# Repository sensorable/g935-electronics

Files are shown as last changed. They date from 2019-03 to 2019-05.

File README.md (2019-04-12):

# Sensorable Open Source Camera
### Electronics and assembly

Sensorable camera is a low power edge computer for smart applications with limited power and bandwidth.
It is based on Samsung G935F smartphone board with auxiliary chassis and electronics.

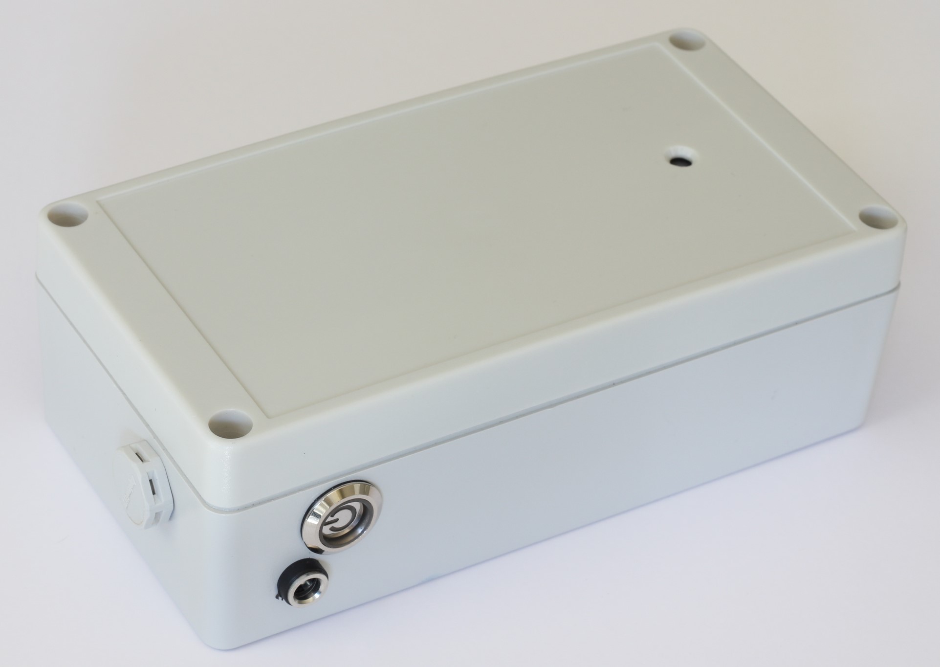
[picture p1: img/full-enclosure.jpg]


**Applications:**
* outdoor security
* remote site monitoring
* beach / nature cams
* traffic monitoring
* vehicle counting
* ALPR / ANPR
* speed control and monitoring

## Main components
* G935F board with a rear camera and antennas
* [custom G935f chassis](https://github.com/sensorable/g935-enclosure)
* [Hammonds IP65 enclosure](https://www.hammfg.com/part/RP1170)
* [auxiliary PSU](https://github.com/sensorable/g935-electronics/tree/master/psu)
* [power](https://github.com/sensorable/g935-electronics/tree/master/pwr-conn) and [USB connectors](https://github.com/sensorable/g935-electronics/tree/master/usb-conn)

The camera can be assembled, programmed, tested and deployed by a sufficiently skilled technician.  

See _BOM-combined.csv_ for the full list of parts.

## Packaging options

* Chassis only for OEM embedding: 155mm x 75mm x 15mm
* Unsealed enclosure for OEM embedding: 165mm x 86mm x 20mm
* Sealed enclosure for external use: 165mm x 86mm x 56mm

The sealed enclosure may include an optional battery pack. See https://github.com/sensorable/batt-pack for more info.

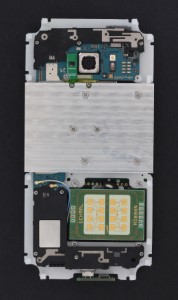
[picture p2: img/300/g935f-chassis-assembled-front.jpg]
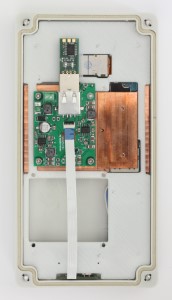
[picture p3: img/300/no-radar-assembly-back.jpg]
 

## Auxiliary components

The chassis has mounting options for a few auxiliary components. They can also be connected externally via USB or RS232.

* Built-in Houston-Radar SS400
* Built-in generic OEM radar
* USB/RS232 adapter
* External Houston-Radar
* External AGD radar

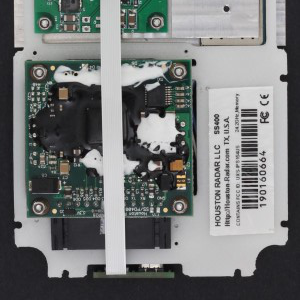
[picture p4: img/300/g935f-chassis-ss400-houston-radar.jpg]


## Ordering and assembly

This is only a high level overview to give you an idea what's involved. We recommend getting in touch with us to help you with your production run.

Check the combined BOM for the full list of components and recommended suppkiers. We tried to minimise the number of suppliers and use only the reputable ones: 

* **Elelctronic parts**: DigiKey
* **Fastenings**: Accu
* **PCB**: JlcPCB
* **PCBA**: JlcPCB or your local PCBA specialist

The final assembly is expected to be done in-house or by a __trusted__ local embedded systems specialist as it involves testing, loading the software and configuring the devices.

See other repositories for the mechanical (chassis) and software (ROM, tools, apps, etc).

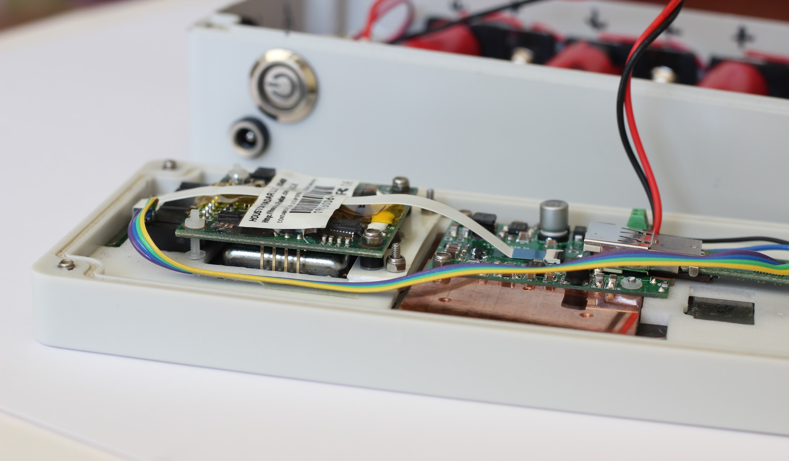
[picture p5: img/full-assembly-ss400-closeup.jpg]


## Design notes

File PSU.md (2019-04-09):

# Sensorable Open Source Camera
### Power Supply Unit

The PSU board converts a single 12v input into multiple voltages needed by the G935F board and auxiliary device. Also, it acts as a connector between a radar, a USB/RS232 converter and the G935F.

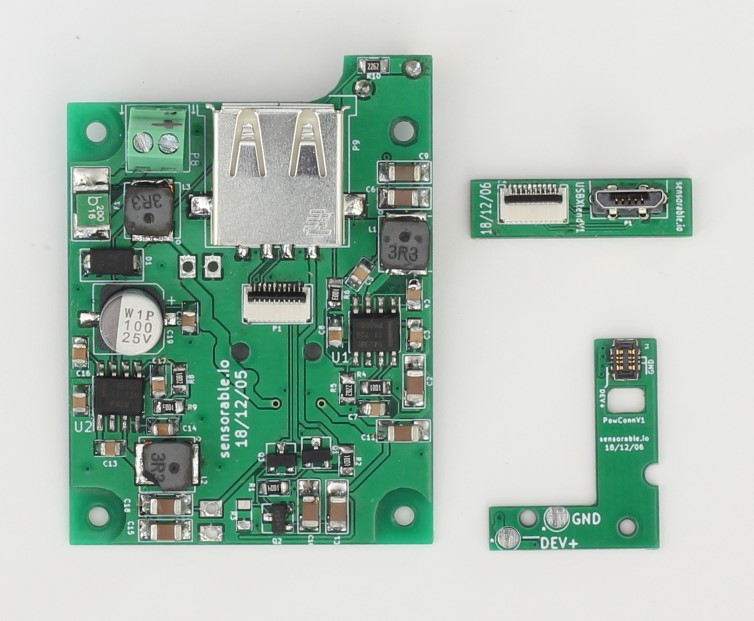
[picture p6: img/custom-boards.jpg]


## Specification

* **Max input voltage:** 14V working voltage
* **Min input voltage:** 6v
* **Max operating current:** 2A
* **Size**: 50mm x 37mm x 9mm

#### Protection

* **Fuse hold/trip current:** 2A/3.5A
* **Input protection:** unipolar Zener diode, 14V working voltage, clamps to 23V @ 17A 
* **Overvoltage protection:** input clamp will cause resettable fuse to blow at sustained voltages exceeding 16V 
* **Reverse polarity protection:** input clamp will cause resettable fuse to blow at sustained reverse voltages exceeding -1V

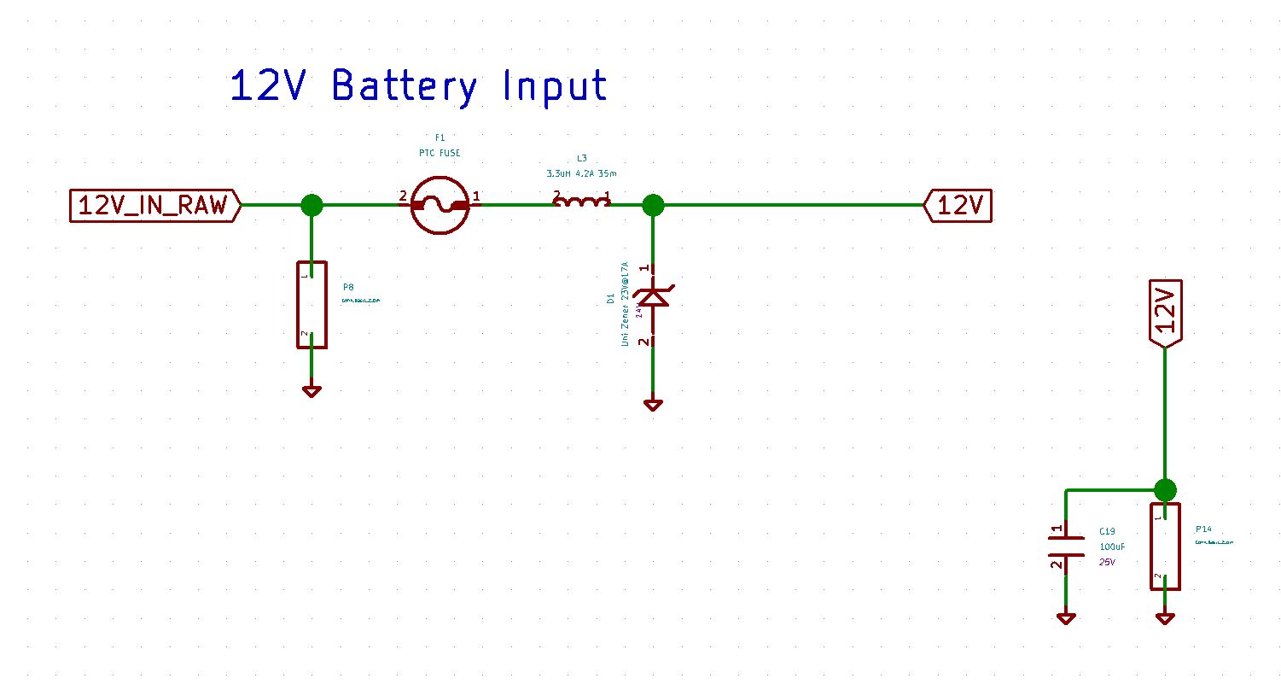
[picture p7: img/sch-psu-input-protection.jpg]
input protection


#### Overview

A 12V input is LC filtered (L3, C19). The input is protected by a resettable fuse and a zener diode (F1,D1).
The 12V input is converted to 4.2V and 5.0V by the same buck converter design, U1,U2. 
4.2V emulates a lithium ion battery. 5.0V is used for USB power.

* Spring loaded pins P4/P5 provide DEV+ as an output.
* The USB module is supplied with 5v through the onboard USB connector.
* The radar can be powered up directly from the source or after the protection circuit on the board.
* The FFC connector links G935F board with the USB module. 

#### Buck Converters:
The buck converters are based one TPS54339E converter. These contain an "ECO" mode, for high efficiency at low loads. 
Datasheet link: http://www.ti.com/lit/ds/slvsbm0/slvsbm0.pdf

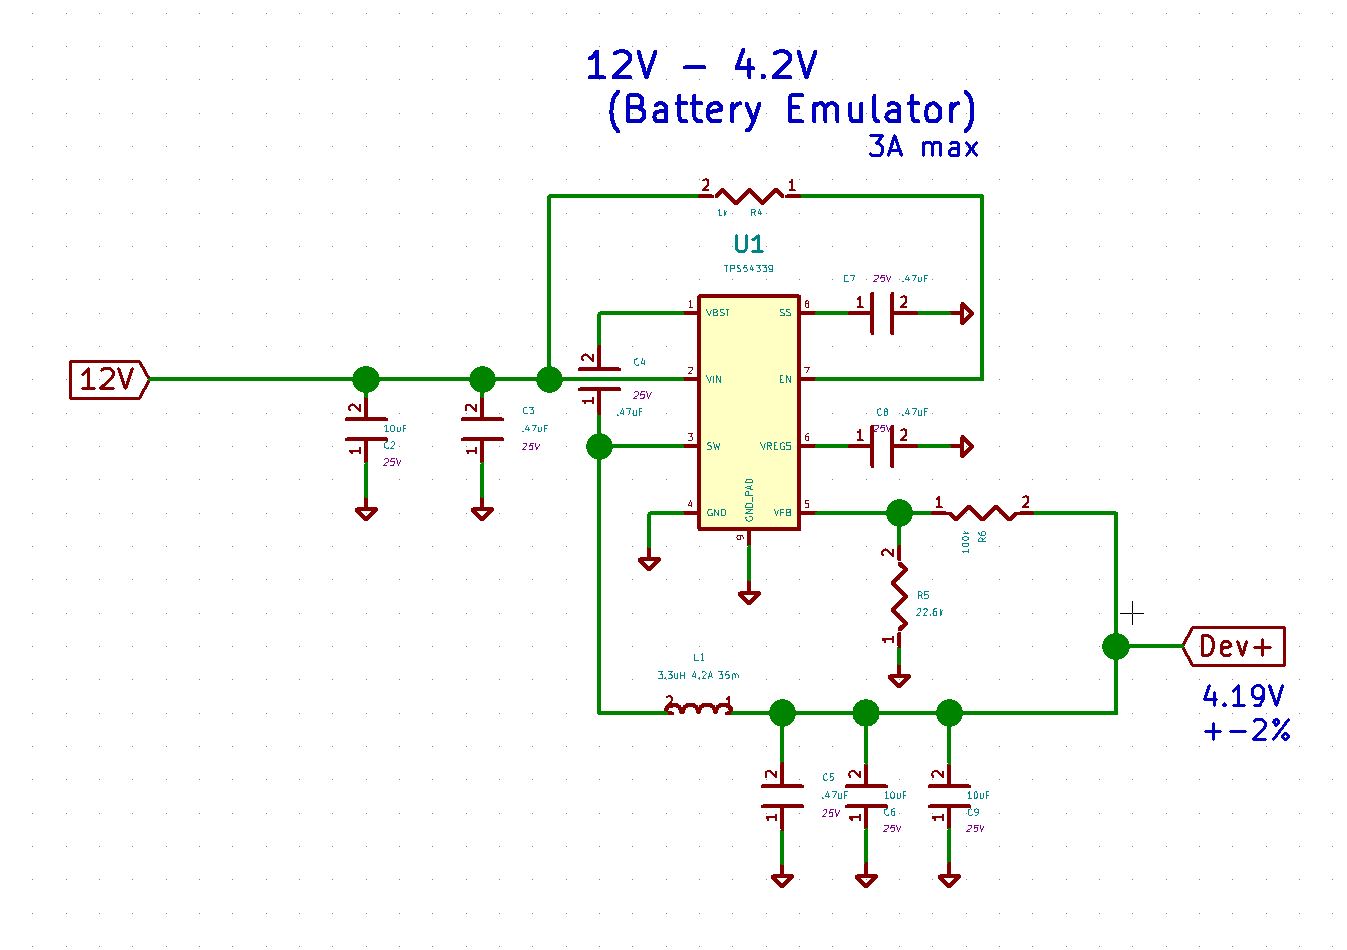
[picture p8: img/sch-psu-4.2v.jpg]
4.2v
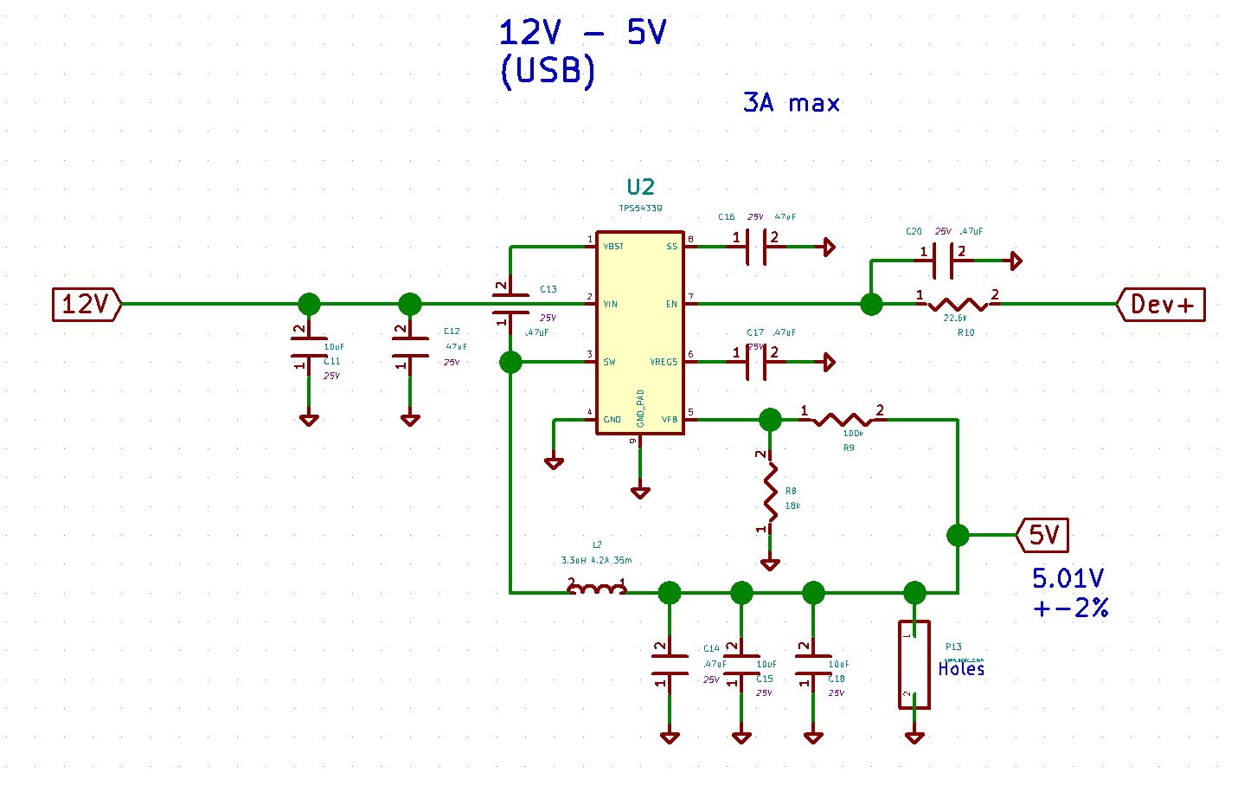
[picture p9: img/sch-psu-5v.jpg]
5v
 

* **Max input:** 23V
* **Outputs:** 4.19V / 5.01V 
* **Output current protection** (either supply): 3.5A - 5.7A; 4.1A nominal
* **Function: current foldback** (voltage droop) until voltage drops to 65% of nominal value. Then converter shuts off and soft restarts.

Efficiency should track what is found in the datasheet, seen below at 12V input: 
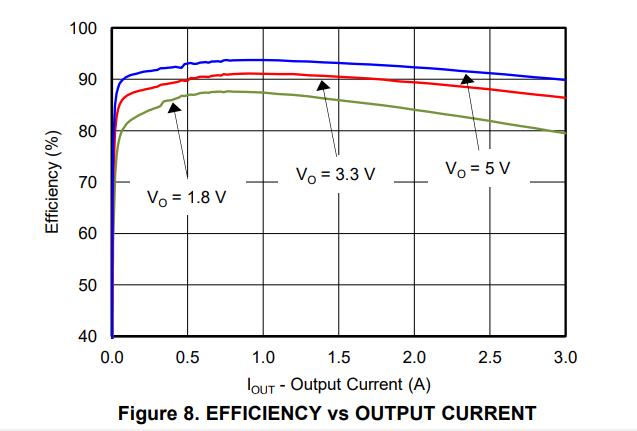
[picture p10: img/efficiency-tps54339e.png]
tps


Efficiency should be around 90% for most loads experienced. 
Only 1% of the loss is in the inductor. As such, there aren't many improvements that can be made to increase efficiency. A fast schottky diode on the switch node (in parallel with the internal switches) would improve efficiency marginally.

#### USB OTG Toggle Circuitry

The USB OTG Toggle circuitry is a one-time impulse that allows the G935F board to boot up.

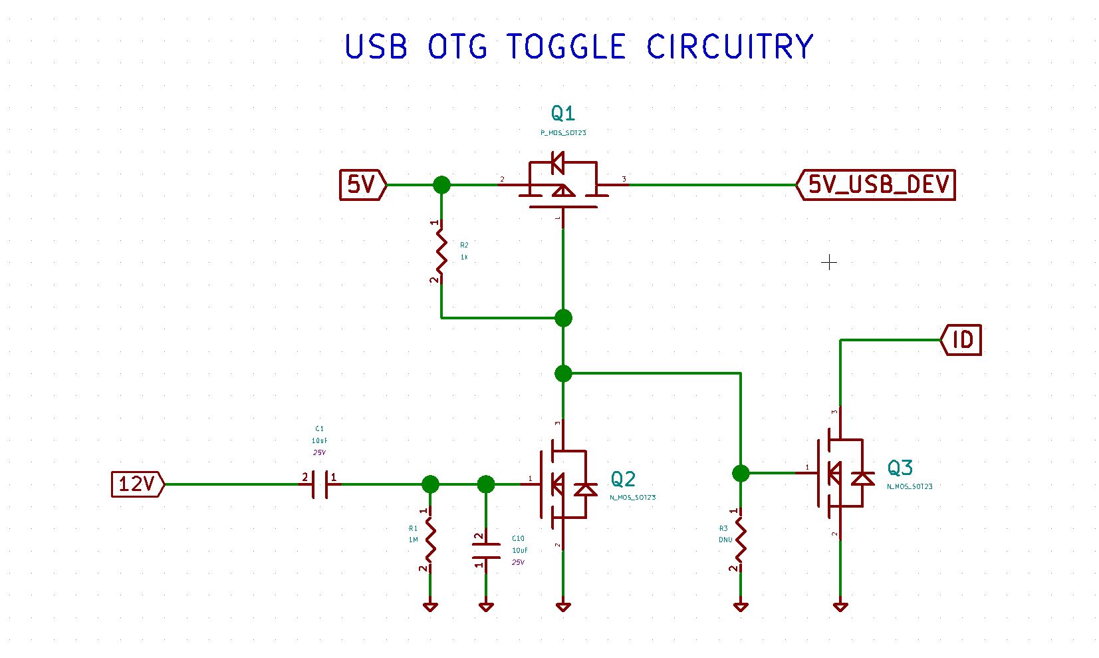
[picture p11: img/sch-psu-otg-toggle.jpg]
otg


R1/C10 form a very slow filter (10s). If the "12V" rail raises up to 12V faster than 10s (as it does when first switched on), then the capacitive divider of C1/C10 will cause Q2 to turn on. Q2 will remain on for ~10s or so, until R1 discharges it. 

Q2 is just an inverter, and the action turns on Q1, applying 5V to the devices USB port. 

The result is several seconds, upon power-up, where the device gets 5V on it's USB port. After that, the 5V is no longer provided to the device.

While 5V is ON, ID is floating due to mosfet Q3 used as another inverter. 
While 5V is OFF, ID is driven to 0V.

This completes the startup logic.

The timing is calculated for Vin = 12v. Lower Vin will turn the OTG mode ON faster.

#### Connectors

**10 pin FFC connector**: provides USB connector between the USB module and G935F board. Take care inserting and removing the FFC cable. Use a piece of tape under the FFC cable to fix it in place after insertion.

**12v input terminal block**: use 26AWG - 20AWG wires, 4.5mm stripping length. There are no markings on the connector or the board. Use a sticker or a permanent marker to clearly indicate +/- terminals.

[photo]: img/custom-boards.jpg
[4.2v]: img/sch-psu-4.2v.jpg
[5v]: img/sch-psu-5v.jpg
[input protection]: img/sch-psu-input-protection.jpg
[otg]: img/sch-psu-otg-toggle.jpg
[tps]: img/efficiency-tps54339e.png

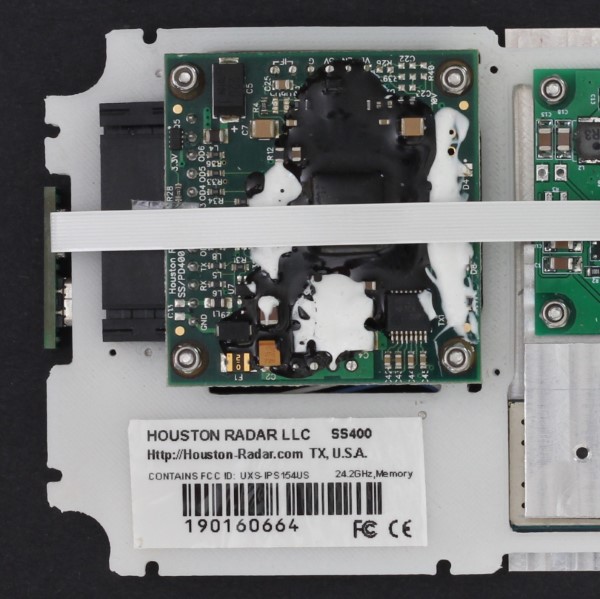
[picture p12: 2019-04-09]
img/g935f-chassis-ss400-houston-radar.jpg

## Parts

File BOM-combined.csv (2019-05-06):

Part name | Man part number | Sup part number | Manufacturer | Datasheet | Supplier link | Qty | Supplier | Reference | Footprint | Item ID
S7 board | G935F motherboard |  | Samsung |  | https://www.aliexpress.com/item/32gb-Original-unlocked-for-Samsung-Galaxy-S7-edge-G935F-motherboard-with-Chips-Europe-version-for-S7/32808370192.html | 1 | AliExpress | Mobo assembly
S7 USB Flex | G935F flex |  | Samsung |  | https://www.aliexpress.com/item/32gb-Original-unlocked-for-Samsung-Galaxy-S7-edge-G935F-motherboard-with-Chips-Europe-version-for-S7/32808370192.html | 1 | AliExpress | Mobo assembly
S7 antenna wires (white + blue) | G935 antenna wires |  | Samsung |  | https://www.aliexpress.com/item/5-Pari-lot-OEM-Signal-Antennas-Spare-Parts-for-Samsung-Galaxy-S7-Edge-SM-G935-G935/32699047662.html | 1 | AliExpress | Mobo assembly
S7 rear cam | G935 Hero 2 or Sony rear camera |  | Samsung |  | https://www.aliexpress.com/item/5-Pari-lot-OEM-Signal-Antennas-Spare-Parts-for-Samsung-Galaxy-S7-Edge-SM-G935-G935/32699047662.html | 1 | AliExpress | Mobo assembly
S7 top antenna panel | G935F top antenna panel |  | Samsung |  | https://www.aliexpress.com/item/5-pcs-lot-Original-Antenna-Cover-Replacement-For-Samsung-Galaxy-S7-edge-G935-G935F/32724024982.html | 1 | AliExpress | Mobo assembly
S7 loud speaker + GSM antenna panel | G935F bottom antenna panel |  | Samsung |  | https://www.aliexpress.com/item/5-pcs-lot-OEM-Buzzer-Ringer-Loudspeaker-Assembly-Part-for-Samsung-Galaxy-S7-Edge-G935-G935F/32666237004.html | 1 | AliExpress | Mobo assembly
S7 SIM tray | G935 SIM tray |  | generic |  | https://www.aliexpress.com/item/5-pcs-lot-OEM-For-Samsung-Galaxy-S7-edge-G935-G935F-G935A-Dual-Sim-Card-Reader/32664675912.html | 1 | AliExpress | Mobo assembly
M1.4 x 5mm screw for plastic pan head |  |  | generic |  | https://www.aliexpress.com/item/500pcs-lot-M1-M1-2-M1-4-M1-7-Stainless-steel-pan-head-philips-type-b/32813683228.html | 12 | AliExpress | Mobo assembly
Glass cover |  |  | generic |  | https://www.aliexpress.com/item/50-pcs-lot-Original-for-Samsung-Galaxy-S7-G930-Back-Rear-Camera-Glass-Lens-Replacement-Glass/32686499894.html | 1 | AliExpress | Front of enclosure
Double sided tape, long life, water resitant |  |  | d.i.y. |  |  | 1 |  | For glass cover
USB to FFC adapter board |  |  | custom PCBA |  | https://jlcpcb.com/ | 1 | JLC PCB | See below for details
Power to FFC adapter board |  |  | custom PCBA |  | https://jlcpcb.com/ | 1 | JLC PCB | See below for details
PSU board |  |  | custom |  | https://jlcpcb.com/ | 1 | JLC PCB | See below for details
Bottom heat sink, 2mm flat, drilled |  |  | custom |  | https://kszyc.en.alibaba.com/ | 1 | KSZYC | Mobo assembly
Top heat sink, 6mm, machined, tapped |  |  | custom |  | https://kszyc.en.alibaba.com/ | 1 | KSZYC | Mobo assembly
RS232 adapter | USB-RS232-PCBA | 768-1066-ND | FTDI | http://www.ftdichip.com/Support/Documents/DataSheets/Cables/DS_USB_RS232_PCB.pdf | https://www.digikey.com/product-detail/en/ftdi-future-technology-devices-international-ltd/USB-RS232-PCBA/768-1066-ND/2402470 | 1 | DigiKey
Graphite heat transfer sheet | EYG-A091201F |  | Panasonic | https://industrial.panasonic.com/cdbs/www-data/pdf/AYA0000/AYA0000C27.pdf | https://www.digikey.com/product-detail/en/panasonic-electronic-components/EYG-A091201F/P19031-ND/5844858 | 1 | DigiKey | Top and bottom heat sinks
Heat transfer pad | TGX-150-150-0.5-0 |  | t-Global | http://www.tglobaltechnology.com/datasheets/TG-X.pdf | https://www.digikey.com/product-detail/en/t-global-technology/TGX-150-150-0.5-0/1168-1351-ND/3042180 | 0.25 | DigiKey | Mobo to heatsinks
Breathable vent | VENT-PS1YGY-N8001 | 1754-1229-ND | Amphenol LTW | http://www.amphenolltw.com/2012download/2D%20PDF/18_Vent%20Connectors/VENT-PS1XXX-XXXXX.pdf | https://www.digikey.com/product-detail/en/amphenol-ltw/VENT-PS1YGY-N8001/1754-1229-ND/7898284 | 1 | DigiKey | Back of enclosure
SS washer 11-16 x 0.5 |  |  |  |  |  |  |  | Required if the vent is threaded into the wall of the enclosure and no nut is used.
Chassis |  |  | custom 3D print |  | http://www.clone3d.co.nz/ | 1 | Clone 3D | Main plate
Enclosure | RP1170 |  | Hammond | https://www.hammfg.com/part/RP1170 | https://www.digikey.com/product-detail/en/hammond-manufacturing/RP1170/HM5793-ND/2570607 | 1 | HiQ | Main enclosure
M2 x 12mm SS CSK machine screw | SIK-M2-12-A2 |  | Accu |  | https://www.accu.co.uk/en/phillips-countersunk-screws/65890-SIK-M2-12-A2 | 4 | Accu | Heatsinks to chassis and PSU
M2 x 5mm SS CSK machine screw | SIK-M2-5-A2 |  | Accu |  | https://www.accu.co.uk/en/phillips-countersunk-screws/65897-SIK-M2-5-A2 | 2 | Accu | Heat sink to heatsink
M2 SS nut | HPN-M2-A2 |  | Accu |  | https://www.accu.co.uk/en/hexagon-nuts/7884-HPN-M2-A2 | 8 | Accu | PSU PCB to chassis
M2 fiber washer, 0.81mm | 3111 | 36-3111-ND | Keystone Electronics |  | https://www.digikey.com/product-detail/en/keystone-electronics/3111/36-3111-ND/315856 | 2 | DigiKey | Master board, between PSU PCB and heatsink
M2 x 12mm SS CSK machine screw | SIK-M2-12-A2 |  | Accu |  | https://www.accu.co.uk/en/phillips-countersunk-screws/65890-SIK-M2-12-A2 | 4 | Accu | Radar to chassis
M2 SS nut | HPN-M2-A2 |  | Accu |  | https://www.accu.co.uk/en/hexagon-nuts/7884-HPN-M2-A2 | 8 | Accu | Radar to chassis
M2 fiber washer, 1.5mm | 3366 | 36-3366-ND | Keystone Electronics |  | https://www.digikey.com/product-detail/en/keystone-electronics/3366/36-3366-ND/315971 | 16 | DigiKey | Radar only, supports
Radar cable assembly | 110990080 | 1597-1502-ND | Seeed Technology | https://media.digikey.com/pdf/Data%20Sheets/Seeed%20Technology/110990080_Web.pdf | https://www.digikey.com/product-detail/en/110990080/1597-1502-ND/5487929/?itemSeq=287487925 | 0.2 | DigiKey | Optional lead for internal SS400 radar
PCB |  |  |  |  | https://jlcpcb.com/ | 1 | JLC PCB
PCBA |  |  |  |  | https://jlcpcb.com/ | 1 | JLC PCB
Total | 219.5
Custom PCBA parts are listed below
USB to FFC adapter board
FFC connector | 5034801000 | WM1389CT-ND | Molex | https://www.molex.com/pdm_docs/sd/5034801000_sd.pdf | https://www.digikey.com/product-detail/en/molex-llc/5034801000/WM1389CT-ND/2356643 | 1 | DigiKey | P2
USB plug | USB3150-30-130-A | 2073-USB3150-30-130-ACT-ND | GCT | https://gct.co/connector/usb3150 | https://www.digikey.com/product-detail/en/gct/USB3150-30-130-A/2073-USB3150-30-130-ACT-ND/9859720 | 1 | DigiKey | P1
USB FFC | 152660102 | WM22883-ND | Molex | https://www.molex.com/pdm_docs/sd/152660102_sd.pdf | https://www.digikey.com/products/en?keywords=152660102 | 1 | DigiKey | Master to USB
Power to FFC adapter board
SlimStack batt connector | 5050040810 | WM11285CT-ND | Molex | https://www.molex.com/pdm_docs/sd/5050040810_sd.pdf | https://www.digikey.com/product-detail/en/molex-llc/5050040810/WM11285CT-ND/5300374 | 1 | DigiKey | P1
Master Board
DNU | DNU |  | DNU |  |  | 0 |  | P2,P3,P6,P7,R3,P10,P11,P13,P14 | DNU | 1
CONN PIN SPRING-LOADED | 0906-2-15-20-75-14-11-0 | ED8182-ND | Mill-Max | https://www.mill-max.com/assets/pdfs/metric/025M.pdf | https://www.digikey.com/products/en?keywords=0906-2-15-20-75-14-11-0 | 2 | DigiKey | P4,P5 | CONN_1_PADnHOLE_2.2mmx.8mm | 2
10 pin FFC connector | 5034801000 | WM1389CT-ND | Molex | https://www.molex.com/pdm_docs/sd/5034801000_sd.pdf | https://www.digikey.com/product-detail/en/molex-llc/5034801000/WM1389CT-ND/2356643 | 1 | DigiKey | P1 | CONN_5034801000_MOLEX_FFC_10pin | 3
External connector (screws) | 1725656 | 1725656 | Phoenix Contact | https://media.digikey.com/pdf/Data%20Sheets/Phoenix%20Contact%20PDFs/1725656.pdf | https://www.digikey.com/product-detail/en/phoenix-contact/1725656/277-1273-ND/267462 | 1 | DigiKey | P8 | TERM_BLK_2_SIDE_2.54MM | 4
USB-A socket | 292303-9 | A108853CT-ND | TE Connectivity | https://www.te.com/commerce/DocumentDelivery/DDEController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 | https://www.digikey.com/product-detail/en/te-connectivity-amp-connectors/292303-9/A108853CT-ND/4031485 | 1 | DigiKey | P9 | CONN_RCPT_USB2_TYPEA_RA_TE | 5
N_MOS_SOT23 | DMN63D8L-7 | DMN63D8L-7 | Diodes Incorporated | https://www.diodes.com/assets/Datasheets/DMN63D8L.pdf | https://www.digikey.com/product-detail/en/diodes-incorporated/DMN63D8L-7/DMN63D8L-7DICT-ND/5699723 | 2 | DigiKey | Q2,Q3 | SOT-23 | 6
P_MOS_SOT23 | DMG2305UX-13 | DMG2305UX-13DICT-ND | Diodes Inc | https://www.diodes.com/assets/Datasheets/DMG2305UX.pdf | https://www.digikey.com/product-detail/en/diodes-incorporated/DMG2305UX-13/DMG2305UX-13DICT-ND/4251589 | 1 | DigiKey | Q1 | SOT-23 | 7
1k | RC0805FR-071KL | 311-1.00KCRCT-ND | Yageo | http://www.yageo.com/documents/recent/PYu-RC_Group_51_RoHS_L_9.pdf | https://www.digikey.com/product-detail/en/yageo/RC0805FR-071KL/311-1.00KCRCT-ND/730391 | 2 | DigiKey | R2,R4 | 0805_Medium_Pads | 8
10uF | C3216X7R1E106K160AB | 445-7705-1-ND | TDK Corporation | https://product.tdk.com/info/en/documents/chara_sheet/C3216X7R1E106K160AB.pdf | https://www.digikey.com/product-detail/en/tdk-corporation/C3216X7R1E106K160AB/445-7705-1-ND/2733777 | 8 | DigiKey | C1,C10,C2,C6,C9,C11,C15,C18 | 1206_Big-Pads | 9
1M | RC0805FR-071ML | 311-1.00MCRCT-ND | Yageo | http://www.yageo.com/documents/recent/PYu-RC_Group_51_RoHS_L_9.pdf | https://www.digikey.com/product-detail/en/yageo/RC0805FR-071ML/311-1.00MCRCT-ND/730392 | 1 | DigiKey | R1 | 0805_Medium_Pads | 10
TPS54339 | TPS54339EDDAR | 296-40793-1-ND | TI | http://www.ti.com/lit/ds/symlink/tps54339e.pdf | https://www.digikey.com/product-detail/en/texas-instruments/TPS54339EDDAR/296-40793-1-ND/5178670 | 2 | DigiKey | U1,U2 | SOIC-8-1EP_3.9x4.9mm_Pitch1.27mm | 11
.47uF | C0805C474K3RACTU | 399-8098-1-ND | KEMET | https://api.kemet.com/component-edge/download/datasheet/C0805C474K3RACTU.pdf | https://www.digikey.com/product-detail/en/kemet/C0805C474K3RACTU/399-8098-1-ND/3471821 | 11 | DigiKey | C3,C4,C7,C8,C5,C12,C13,C16,C17,C14,C20 | 0805_Medium_Pads | 12
3.3uH 4.2A 35m | VLS5045EX-3R3N | 445-174398-1-ND | TDK | https://product.tdk.com/info/en/catalog/datasheets/inductor_automotive_power_vls5045ex-ca_en.pdf | https://www.digikey.com/product-detail/en/tdk-corporation/VLS5045EX-3R3N/445-174398-1-ND/5880162 | 3 | DigiKey | L1,L2,L3 | IND_2_5x5mm | 13
100k | RC0805FR-07100KL | 311-100KCRCT-ND | Yageo | http://www.yageo.com/documents/recent/PYu-RC_Group_51_RoHS_L_9.pdf | https://www.digikey.com/product-detail/en/yageo/RC0805FR-07100KL/311-100KCRCT-ND/730491 | 2 | DigiKey | R6,R9 | 0805_Medium_Pads | 14
18k | RC0805FR-0718KL | 311-18.0KCRCT-ND | Yageo | http://www.yageo.com/documents/recent/PYu-RC_Group_51_RoHS_L_9.pdf | https://www.digikey.com/product-detail/en/yageo/RC0805FR-0718KL/311-18.0KCRCT-ND/730591 | 1 | DigiKey | R8 | 0805_Medium_Pads | 15
22.6k | RC0805FR-0722K6L | 311-22.6KCRCT-ND | Yageo | http://www.yageo.com/documents/recent/PYu-RC_Group_51_RoHS_L_9.pdf | https://www.digikey.com/product-detail/en/yageo/RC0805FR-0722K6L/311-22.6KCRCT-ND/730687 | 2 | DigiKey | R5,R10 | 0805_Medium_Pads | 16
PTC FUSE | 0ZCG0200AF2B | 507-2074-1-ND | Bel Fuse | https://www.belfuse.com/resources/CircuitProtection/datasheets/0ZCG%20Nov2016.pdf | https://www.digikey.com/product-detail/en/bel-fuse-inc/0ZCG0200AF2B/507-2074-1-ND/6210551 | 1 | DigiKey | F1 | 1812 | 17
Uni Zener 23V@17A | SMAJ14A | SMAJ14ALFCT-ND | Littelfuse | http://www.littelfuse.com/~/media/electronics/datasheets/tvs_diodes/littelfuse_tvs_diode_smaj_datasheet.pdf.pdf | https://www.digikey.com/product-detail/en/littelfuse-inc/SMAJ14A/SMAJ14ALFCT-ND/762486 | 1 | DigiKey | D1 | SMA | 18
100uF | UWT1E101MCL1GS | 493-2190-1-ND | Nichicon | http://nichicon-us.com/english/products/pdfs/e-uwt.pdf | https://www.digikey.com/product-detail/en/nichicon/UWT1E101MCL1GS/493-2190-1-ND/590165 | 1 | DigiKey | C19 | CAP_SMD_CAN_6.6x6.6mm | 19

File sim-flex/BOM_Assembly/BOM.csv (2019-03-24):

Reference | Value | Footprint | Manufacturer1 | Manufacturer1PartNumber
C1 | 1000pF X7R | Footprints:0603_Medium_Pads | Yageo | AC0603KRX7R8BB102
C2 | 1000pF X7R | Footprints:0603_Medium_Pads | Yageo | AC0603KRX7R8BB102
P2 | NANO_SIM_SF72S006VBAR2500 | Footprints:JAE-SF72S006VBAR2500 | JAE | SF72S006VBAR2500

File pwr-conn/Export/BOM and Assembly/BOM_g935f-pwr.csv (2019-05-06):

Item ID | Reference | Quantity | Value | Footprint | Manufacturer1 | Manufacturer1PartNumber
1 | P1 | 1 | 8Pin_2x4_inline | 8pin_molex_s7BatteryConn_5050040810 | Molex | 5050040810

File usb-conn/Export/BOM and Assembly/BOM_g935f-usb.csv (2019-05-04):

Item ID | Reference | Quantity | Value | Footprint | Manufacturer1 | Manufacturer1PartNumber
1 | P1 | 1 | Conn_USB_5+Shell | CONN_USB3150_microB_THT_vert | GCT | USB3150-30-075-A
2 | P2 | 1 | Conn_Basic_10_pin | CONN_5034801000_MOLEX_FFC_10pin | MOLEX | 5034801000

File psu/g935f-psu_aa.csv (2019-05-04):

Reference | Value | Footprint | Datasheet | Manufacturer1 | Manufacturer1PartNumber | Tolerance | Voltage
P2 | PAD | Footprints:NPTH_2mm |  | MFG1 | MFG1PN
P3 | PAD | Footprints:NPTH_2mm |  | MFG1 | MFG1PN
P4 | PAD | Interfacez:CONN_1_SPRING_TH_1.83x.6mm |  | Mill-Max | 0906-2-15-20-75-14-11-0
P6 | PAD | Footprints:NPTH_2mm |  | MFG1 | MFG1PN
P7 | PAD | Footprints:NPTH_2mm |  | MFG1 | MFG1PN
P5 | PAD | Interfacez:CONN_1_SPRING_TH_1.83x.6mm |  | Mill-Max | 0906-2-15-20-75-14-11-0
P1 | Conn_Basic_10_pin | Footprints:CONN_5034801000_MOLEX_FFC_10pin |  | Molex | 5034801000
P8 | Conn_Basic_2_pin | Footprints:TERM_BLK_2_SIDE_2.54MM |  | Phoenix | 1725656
P9 | Conn_Basic_5_pin_0 | Footprints:CONN_RCPT_USB2_TYPEA_RA_TE |  | TE CONNECTIVITY | 292303-9
Q2 | N_MOS_SOT23 | Footprints:SOT-23 |  | Diodes Inc | DMN63D8L-7
Q1 | P_MOS_SOT23 | Footprints:SOT-23 |  | Diodes Inc | DMG2305UX-13
R2 | 1k | Footprints:0805_Medium_Pads |  | Yageo | RC0805FR-071KL | Tol
R3 | DNU | Footprints:0805_Medium_Pads |  | MFG1 | MFG1PN | Tol
C1 | 10uF | Footprints:1206_Big-Pads |  | TDK | C3216X7R1E106K160AB |  | 25V
R1 | 1M | Footprints:0805_Medium_Pads |  | Yageo | RC0805FR-071ML | 1%
P10 | PAD | Footprints:NPTH_1.5mm |  | MFG1 | MFG1PN
P11 | PAD | Footprints:NPTH_1.5mm |  | MFG1 | MFG1PN
U1 | TPS54339 | Footprints:SOIC-8-1EP_3.9x4.9mm_Pitch1.27mm |  | TI | TPS54339EDDAR
C10 | 10uF | Footprints:1206_Big-Pads |  | TDK | C3216X7R1E106K160AB |  | 25V
C2 | 10uF | Footprints:1206_Big-Pads |  | TDK | C3216X7R1E106K160AB |  | 25V
C3 | .47uF | Footprints:0805_Medium_Pads |  | KEMET | C0805C474K3RACTU |  | 25V
L1 | 3.3uH 4.2A 35m | Footprints:IND_2_5x5mm |  | TDK | VLS5045EX-3R3N
C6 | 10uF | Footprints:1206_Big-Pads |  | TDK | C3216X7R1E106K160AB |  | 25V
C9 | 10uF | Footprints:1206_Big-Pads |  | TDK | C3216X7R1E106K160AB |  | 25V
C4 | .47uF | Footprints:0805_Medium_Pads |  | KEMET | C0805C474K3RACTU |  | 25V
C7 | .47uF | Footprints:0805_Medium_Pads |  | KEMET | C0805C474K3RACTU |  | 25V
C8 | .47uF | Footprints:0805_Medium_Pads |  | KEMET | C0805C474K3RACTU |  | 25V
C5 | .47uF | Footprints:0805_Medium_Pads |  | KEMET | C0805C474K3RACTU |  | 25V
R6 | 100k | Footprints:0805_Medium_Pads |  | Yageo | RC0805FR-07100KL | Tol
U2 | TPS54339 | Footprints:SOIC-8-1EP_3.9x4.9mm_Pitch1.27mm |  | TI | TPS54339EDDAR
C11 | 10uF | Footprints:1206_Big-Pads |  | TDK | C3216X7R1E106K160AB |  | 25V
C12 | .47uF | Footprints:0805_Medium_Pads |  | KEMET | C0805C474K3RACTU |  | 25V
L2 | 3.3uH 4.2A 35m | Footprints:IND_2_5x5mm |  | TDK | VLS5045EX-3R3N
C15 | 10uF | Footprints:1206_Big-Pads |  | TDK | C3216X7R1E106K160AB |  | 25V
C18 | 10uF | Footprints:1206_Big-Pads |  | TDK | C3216X7R1E106K160AB |  | 25V
P13 | Conn_Basic_2_pin | Footprints:CONN_2pin_just_holes_2.54mmPITCH_1mmBigSquareHOLES |  | MFG1 | MFG1PN
R8 | 18k | Footprints:0805_Medium_Pads |  | Yageo | RC0805FR-0718KL | Tol
C13 | .47uF | Footprints:0805_Medium_Pads |  | KEMET | C0805C474K3RACTU |  | 25V
C16 | .47uF | Footprints:0805_Medium_Pads |  | KEMET | C0805C474K3RACTU |  | 25V
C17 | .47uF | Footprints:0805_Medium_Pads |  | KEMET | C0805C474K3RACTU |  | 25V
C14 | .47uF | Footprints:0805_Medium_Pads |  | KEMET | C0805C474K3RACTU |  | 25V
R9 | 100k | Footprints:0805_Medium_Pads |  | Yageo | RC0805FR-07100KL | Tol
R5 | 22.6k | Footprints:0805_Medium_Pads |  | Yageo | RC0805FR-0722K6L | Tol
F1 | PTC FUSE | Footprints:1812 |  | Bel Fuse | 0ZCG0200AF2B | Tol
D1 | Uni Zener 23V@17A | Footprints:SMA |  | Littelfuse | SMAJ14A |  | 14V
L3 | 3.3uH 4.2A 35m | Footprints:IND_2_5x5mm |  | TDK | VLS5045EX-3R3N
P14 | Conn_Basic_2_pin | Footprints:CONN_2pin_just_holes_2.54mmPITCH_1mmBigSquareHOLES |  | MFG1 | MFG1PN
C19 | 100uF | Footprints:CAP_SMD_CAN_6.6x6.6mm |  | Nichicon | UWT1E101MCL1GS |  | 25V
Q3 | N_MOS_SOT23 | Footprints:SOT-23 |  | Diodes Inc | DMN63D8L-7
R4 | 1k | Footprints:0805_Medium_Pads |  | Yageo | RC0805FR-071KL | Tol
R10 | 22.6k | Footprints:0805_Medium_Pads |  | Yageo | RC0805FR-0722K6L | Tol
C20 | .47uF | Footprints:0805_Medium_Pads |  | KEMET | C0805C474K3RACTU |  | 25V

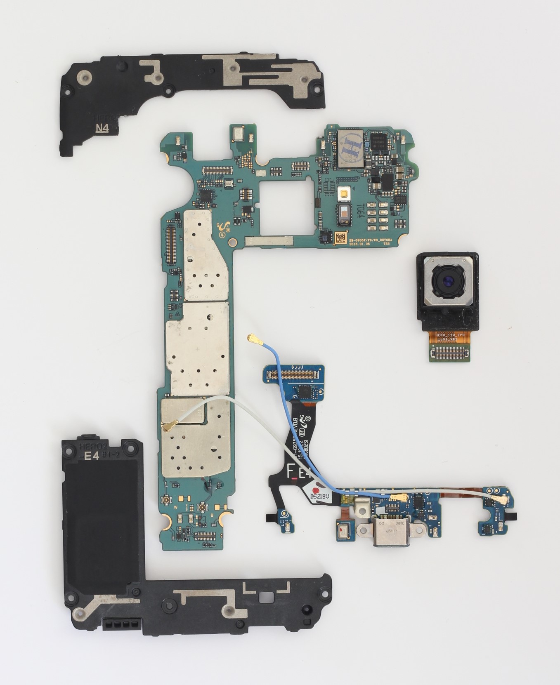
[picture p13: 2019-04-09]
img/g935f-parts.jpg

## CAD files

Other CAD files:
psu/OSHW-Logo-R2000__.dxf
pwr-conn/g935f-pwr.dxf

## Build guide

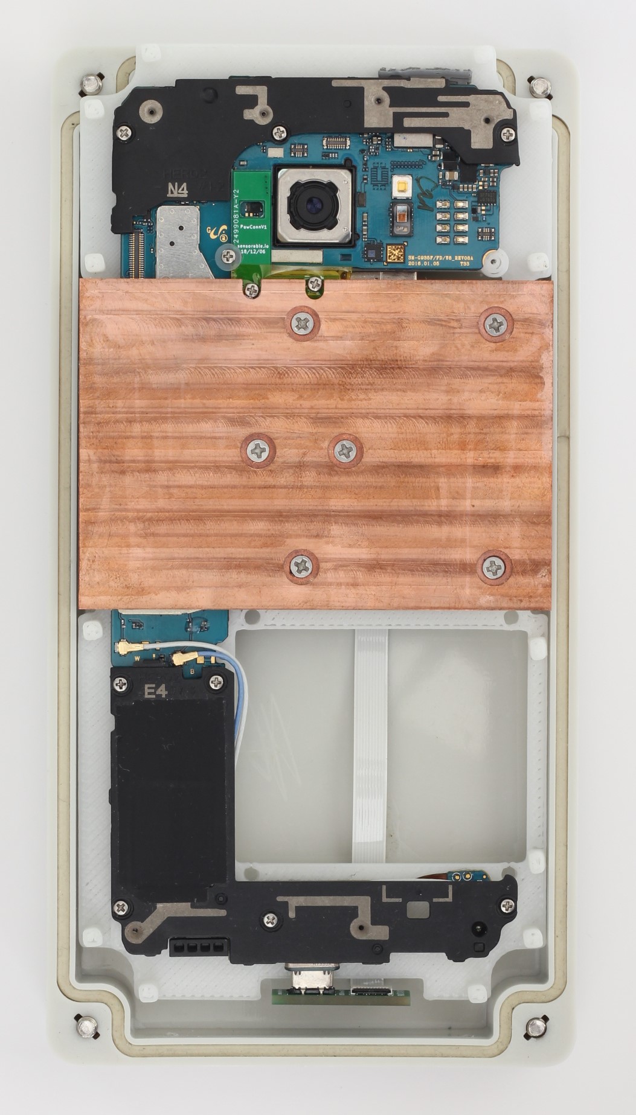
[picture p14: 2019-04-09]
img/no-radar-assembly-front.jpg

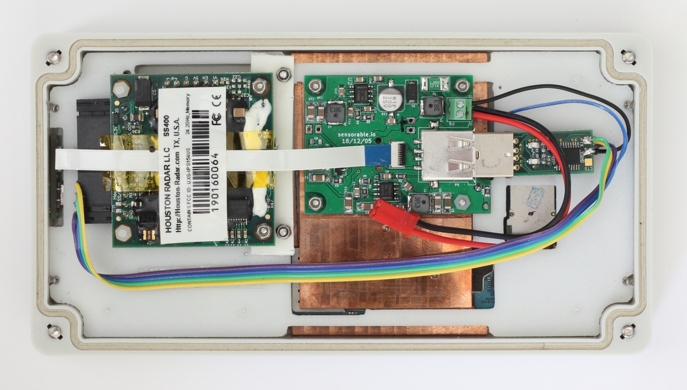
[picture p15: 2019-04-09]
img/full-assembly-with-ss400-radar.jpg

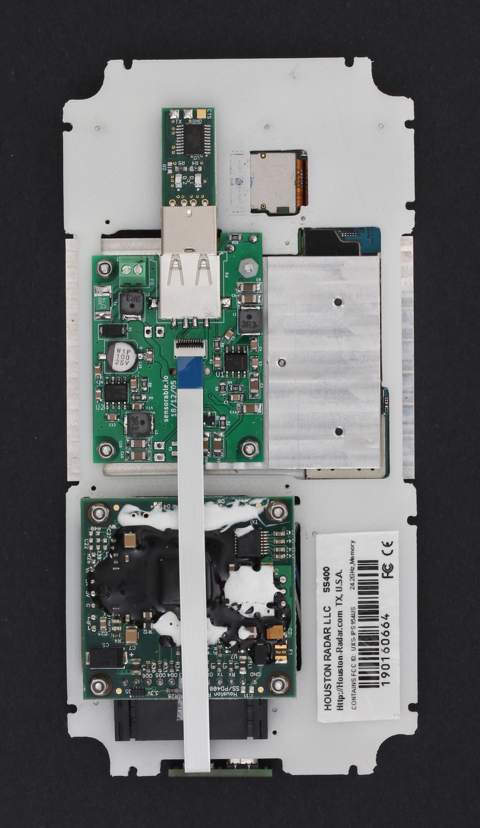
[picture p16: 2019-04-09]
img/g935f-chassis-assembled-back.jpg

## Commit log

2019-03-16 Production proprotype
    [BOM.csv, BOM_Purchasing.csv, TrafMasterV1-B.Cu.dxf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]
2019-03-24 Electronics combined into a single repo.
    [BOM.csv, BOM_Purchasing.csv, PowConnV1-B.Cu.dxf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]
2019-03-24 Initial BOM added.
    [BOM-combined.csv]
2019-04-09 Updated library references.
    [TrafMasterV1.sch]
2019-04-09 KiCad gitignore added.
2019-04-09 Main readme added.
    [BOM-combined.csv]
2019-04-16 Add 12V port silk marking
    Added "12V" "GND" to 12V port.
    [TrafMasterV1.kicad_pcb]
2019-04-16 Minor part, layout, changes
    Smaller hole for spring connector,
    shift ffc cable mounting holes,
    proper copper isolation from screw hole that was missing it
    [TrafMasterV1.kicad_pcb, TrafMasterV1.sch]
2019-04-27 As described in JIRA EL-160
    1. Shift the cutout on the side
    2. Add bigger no-copper space around holes to avoid contact with screw heads
    3. Widen the part with contacts by 1mm
    4. Rename to G935F-PWR
    5. Label with sensorable.io and the date in yyyy-mm-dd format.
    6. Leave all contacts and footprints exactly where they are.
    [PowConnV1.kicad_pcb, pwr-20190420.dxf]
2019-04-27 Updates from JIRA EL-160
    see EL-160.
    add logo, some markings, new spring pin footprint/partnumber, space around screwhole, shift FFC mounting holes.
    [OSHW-Logo-R2000__.dxf, TrafMasterV1.kicad_pcb, TrafMasterV1.sch]
2019-05-01 move FFC hole fix error
    move FFC hole fix error
    [TrafMasterV1.kicad_pcb]
2019-05-03 kicad files, ready for assembly
    as processed for the mfg+assembly .zip
    [PowConnV1.kicad_pcb, PowConnV1.sch]
2019-05-03 Production files. Manufacturing and Assembly
    Files needed for PCB manufacturing and parts purchase an assembly. extra folder for PDF references as well
    [BOM_2019y_05m_03d___13h_52m_50s.csv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]
2019-05-03 zip for manufacuring/assembly
    same files that are in the folder structure are zipped. Send this to a PCBA outfit for assembly.
2019-05-03 updated date/version
    change to may 3 2019
    [PowConnV1.kicad_pcb]
2019-05-03 Ready for production
    Gerber files for manufacturing and assembly, separated by folder.
    KICAD project source files.
    [BOM_2019y_05m_03d___15h_24m_09s.csv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]
2019-05-03 Ready for production, zip for RFQ
    Send this zip to a PCBA outfit for PCB manufacturing, parts purchase, and assembly.
2019-05-03 source file for production files generated
    source file, forgot the PCB with last commit/push
    [TrafMasterV1.kicad_pcb]
2019-05-04 Ready for production
    KiCAD source files and PCB manufacturing and assembly outputs.
    [BOM_2019y_05m_03d___19h_56m_39s.csv, TrafMasterV1_aa.csv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]
2019-05-04 Ready for production
    Send this .zip containing specs, PCB manufacturing outputs, and BOM/Assembly outputs to a PCBA outfit for a quote.
2019-05-06 Moved export files, corrected BOM
    [BOM-combined.csv, BOM-g935f-psu.csv, BOM.csv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]
2019-05-17 fix hole size
    pcb slivers were too small according to jlcpcb. fixed it to line up similar to last build but also a little smaller. should be fine.
    updated .pcb file and relevant gerber outputs (board edge and copper layers)
    [g935f-pwr.kicad_pcb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]
2019-05-17 Same as last commit, forgot to save
    See last commit, forgot to save the file.
    [g935f-pwr.kicad_pcb]
2019-06-17 Added KiCad files for SIM Flex.
    [SIM_FLEX_EXTENDER2lyr.kicad_pcb, SIM_FLEX_EXTENDER2lyr.sch]
